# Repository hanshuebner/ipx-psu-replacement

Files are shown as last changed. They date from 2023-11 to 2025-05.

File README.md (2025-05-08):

# Sun SPARCstation IPC/IPX replacement power supply

I've got tired of unsuccessfully trying to repair the APS-02 power
supply that is built into Sun's SPARCstation IPC and IPX workstations,
so I designed this replacement.  It uses two encapsulated power
supplies and a MAX8215 power supply monitoring chip to generate the
SENS signal.

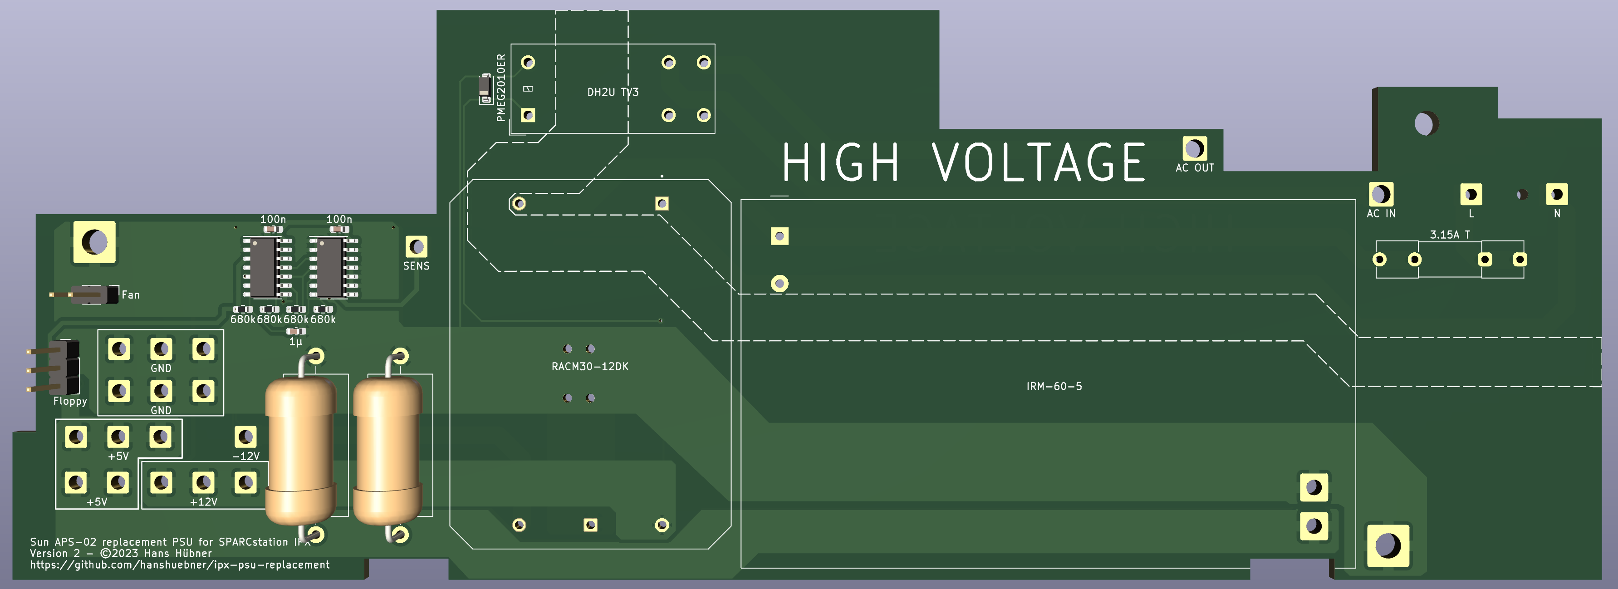
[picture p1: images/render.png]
Rendered v2 PCB


Here's a picture of my version 1 build.  It has the base load
resistors bodged on.  The layout has been revised since:

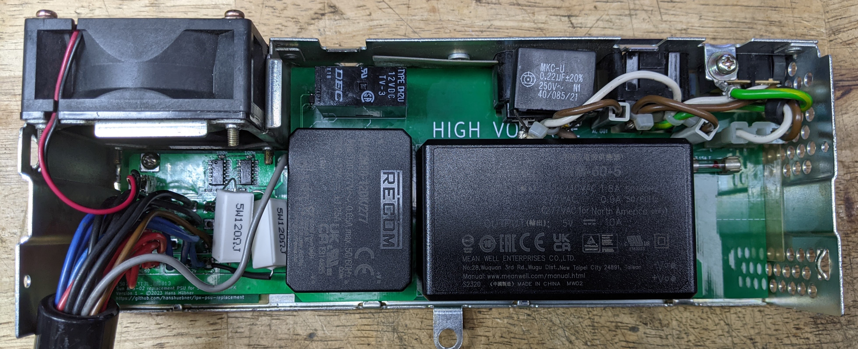
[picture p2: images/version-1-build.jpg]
Version 1 build


Several parts out of the original PSU board are reused and need to be
desoldered:

|Ref |Qnty|Value |Notes |
|----|----|---|---|
|F1  |1 |3.15A T  |Fuse + fuse holder |
|J1  |1 |L |Power input (3 pin, middle pin not connected) |
|J2  |1 |AC IN |Power from IEC input (1 pin) |
|J5  |1 |AC OUT |Power to IEC output (1 pin) |
|J12 |1 |Fan |Power to fan (2 pin) |
|K1  |1 |DH2U TV3 |IEC output relay |
| |1 | |Cable harness including floppy connector |

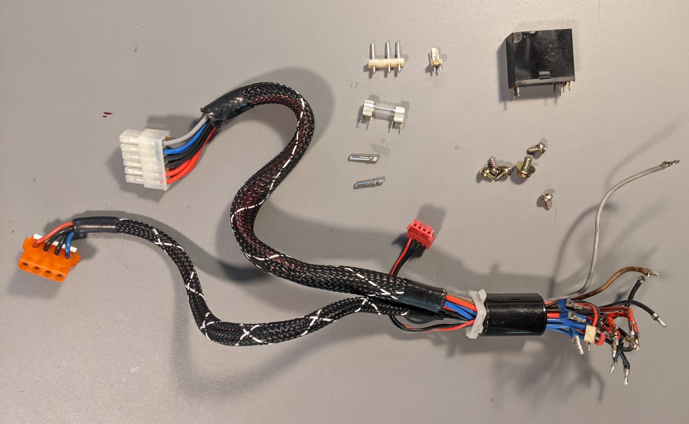
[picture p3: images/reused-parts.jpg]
Reused parts


Another couple of parts need to be bought

|Ref |Qnty|Value |Description |
|---|----|---|---|
|U1 |1 |74HCT11D |Triple 3-input AND, SO-14 |
|U2 |1 |MAX8215CSD |Voltage Monitor IC, SO-14 |
|D1 |1 |PMEG2010ER |20V 1A Planar Schottky barrier rectifier, SOD-123 |
|C1, C2 |2 |100nF |Capacitor bipolar SMD 0603 |
|C3 |1 |1µF |Capacitor bipolar SMD 0603 |
|R1, R2, R3, R4|4 |680kΩ |Resistor SMD 0603 |
|R5, R6 |2 |120Ω |Resistor radial 5W, 20mmx9mmx9mm, 25mm pitch |
|PS1 |1 |IRM-60-5 |MeanWell IRM-60-5 50 Watt AC/DC power supply, 5V, 10A |
|PS2 |1 |RACM30-12DK|RECOM RACM30-12DK/277 30 Watt Dual Output AC/DC power supply, ±12V, ±1250mA |

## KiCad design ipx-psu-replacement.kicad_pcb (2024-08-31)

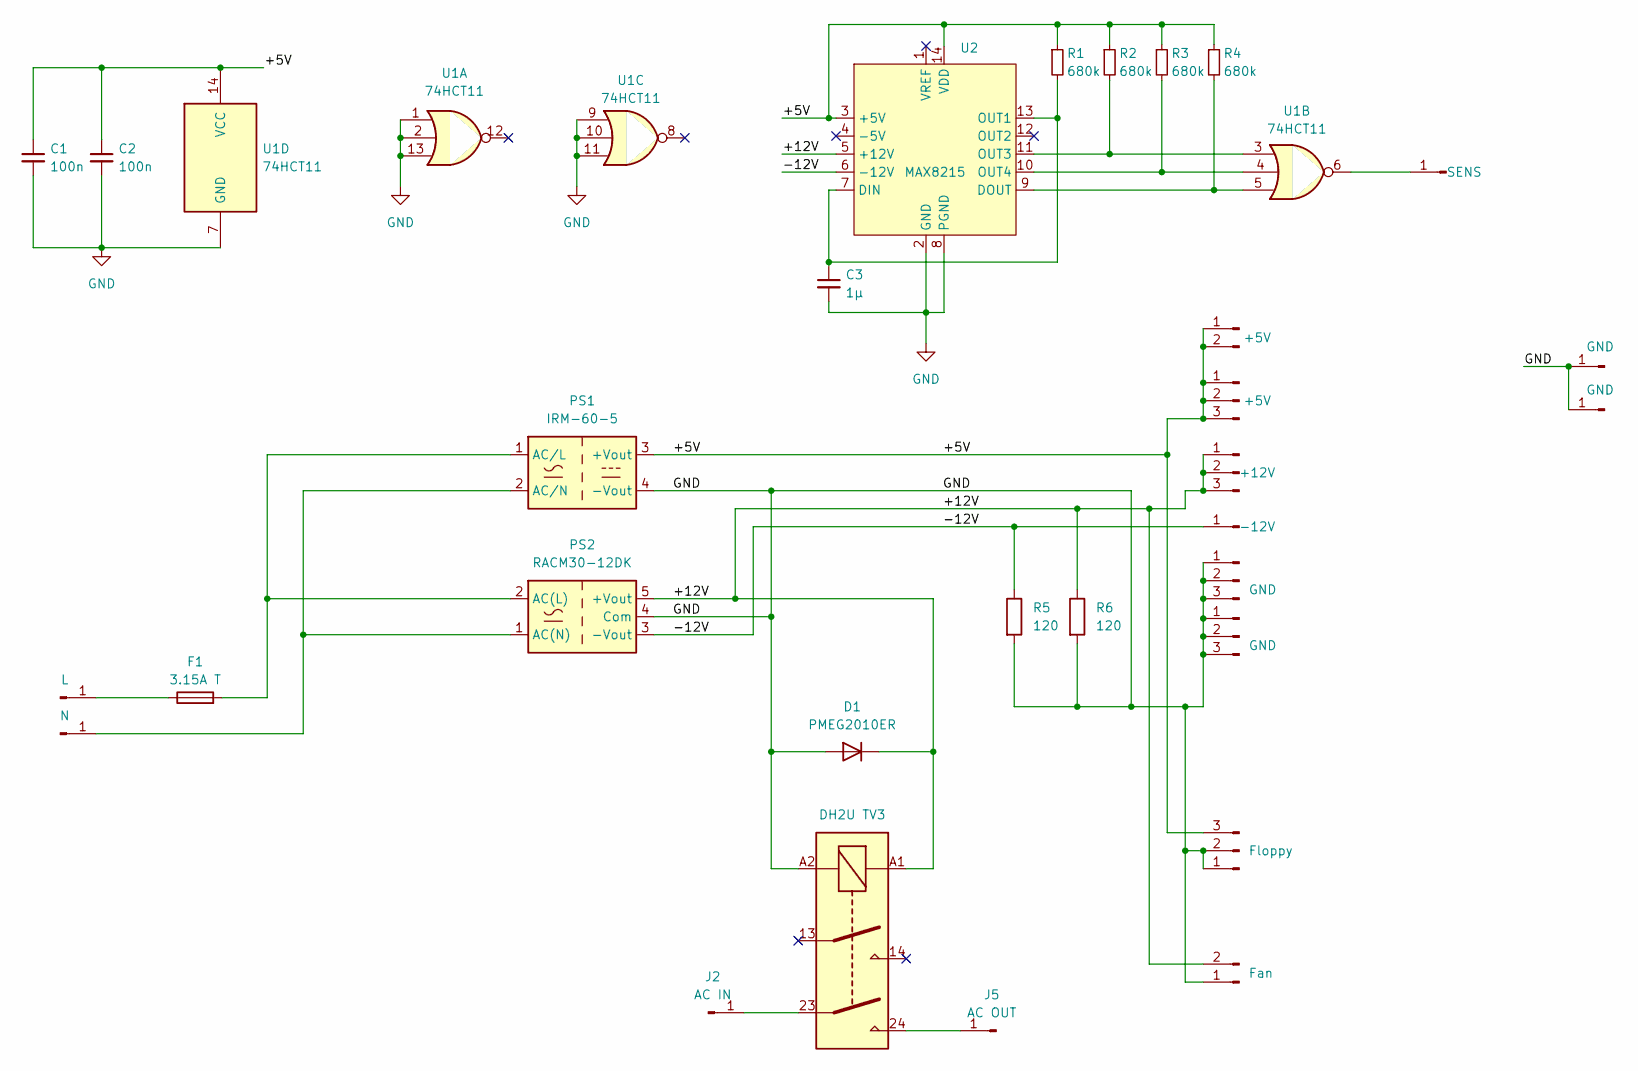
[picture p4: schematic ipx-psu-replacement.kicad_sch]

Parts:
C1, C2: 100n; C_0603_1608Metric_Pad1.08x0.95mm_HandSolder
C3: 1µ; C_0603_1608Metric_Pad1.08x0.95mm_HandSolder
D1: PMEG2010ER; D_SOD-123
F1: 3.15A T; Fuseholder_Clip-5x20mm_Littelfuse_111_Inline_P20.00x5.00mm_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
J1: L; SolderWire-1.5sqmm_1x01_D1.7mm_OD3mm
J2: AC IN; SolderWire-1.5sqmm_1x01_D1.7mm_OD3mm
J3, J11: GND; SolderWire-1.5sqmm_1x03_P6mm_D1.7mm_OD3mm
J4: Floppy; PinHeader_1x03_P2.54mm_Vertical
J5: AC OUT; SolderWire-1.5sqmm_1x01_D1.7mm_OD3mm
J6: N; SolderWire-1.5sqmm_1x01_D1.7mm_OD3mm
J7: +12V; SolderWire-1.5sqmm_1x03_P6mm_D1.7mm_OD3mm
J8: +5V; SolderWire-1.5sqmm_1x02_P6mm_D1.7mm_OD3mm
J9: +5V; SolderWire-1.5sqmm_1x03_P6mm_D1.7mm_OD3mm
J10: -12V; SolderWire-1.5sqmm_1x01_D1.7mm_OD3mm
J12: Fan; PinHeader_1x02_P2.54mm_Vertical
J13: SENS; SolderWire-1.5sqmm_1x01_D1.7mm_OD3mm
J14, J15: GND; SolderWire-2sqmm_1x01_D2mm_OD3.9mm
K1: DH2U TV3; Relay_DPST_Omron_G2RL-2A
PS1: IRM-60-5; Converter_ACDC_MeanWell_IRM-60-xx_THT
PS2: RACM30-12DK; CONV_RACM30-24SK_277
R1, R2, R3, R4: 680k; R_0603_1608Metric_Pad0.98x0.95mm_HandSolder
R5, R6: 120; R_Axial_DIN0922_L20.0mm_D9.0mm_P25.40mm_Horizontal
U1: 74HCT11; SO-14_3.9x8.65mm_P1.27mm
U2: MAX8215; SO-14_3.9x8.65mm_P1.27mm

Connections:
/+5V: C1.1, C2.1, J4.3, J8.1, J8.2, J9.1, J9.2, J9.3, PS1.3 (+Vout), R1.1, R2.1, R3.1, R4.1, U1.14 (VCC), U2.3 (+5V), U2.14 (VDD)
/+12V: D1.1 (K), J7.1, J7.2, J7.3, J12.2, K1.A1, PS2.5 (+Vout), R6.1, U2.5 (+12V)
/-12V: J10.1, PS2.3 (-Vout), R5.1, U2.6 (-12V)
GND: C1.2, C2.2, C3.2, D1.2 (A), J3.1, J3.2, J3.3, J4.1, J4.2, J11.1, J11.2, J11.3, J12.1, J14.1, J15.1, K1.A2, PS1.4 (-Vout), PS2.4 (Com), R5.2, R6.2, U1.1, U1.2, U1.7 (GND), U1.9, U1.10, U1.11, U1.13, U2.2 (GND), U2.8 (PGND)
unnamed: F1.1, J1.1
unnamed: J2.1, K1.23
unnamed: J5.1, K1.24
unnamed: J6.1, PS1.2 (AC/N), PS2.1 (AC(N))
unnamed: J13.1, U1.6
unnamed: F1.2, PS1.1 (AC/L), PS2.2 (AC(L))
unnamed: C3.1, R1.2, U2.7 (DIN), U2.13 (OUT1)
unnamed: R4.2, U1.5, U2.9 (DOUT)
unnamed: R2.2, U1.3, U2.11 (OUT3)
unnamed: R3.2, U1.4, U2.10 (OUT4)

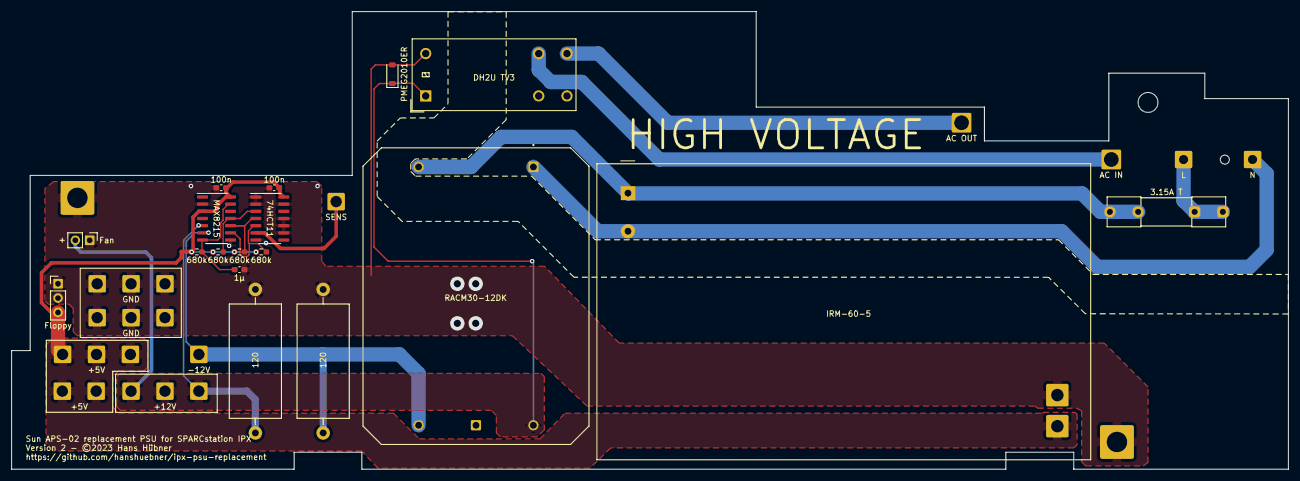
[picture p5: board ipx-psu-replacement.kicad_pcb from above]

Board: 2 copper layers, 226.0 x 81.0 mm, 31 parts (0 on the bottom side), 14 nets.

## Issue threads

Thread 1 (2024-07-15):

Accessory AC Power  - Potentially Incorrect Interpretation

trick-1, 2024-07-15:
Hi there,

I got 5 boards made for my IPX/IPC/Classic collection.

Brining my 1st board up and I noted that the AC IN and AC OUT are not interpreted the same as on the original PSU.

On my original PSU I can clearly see that there is a path from the Active and Neutral to one side of the relay and then from the otherside of the relay to the accessory power connector.  I cannot work out a sound way to wire at this point.

hanshuebner, 2024-07-15:
Can you send a couple photos illustrating the problem?  Maybe you have a different version of the PSU?  Do all the PSUs that you have look the same?  I have used the board for three IPXen and they were all the same, but that is just a small sample of course.

trick-1, 2024-07-15:
In the following the brown and white wires come in from the mains.
The blue and black wires go out to the accessory socket and are switched by the relay.
You can see the mask for the relay on the top side.
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
On this image you can see the foot print of the relay. on the left of the relay is the input from the mains and on the right is the output to the accessory socket.
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
ST3 and ST4 are the output to the accessory socket. ST2 and the hole near the word "SAME" are the inputs from the mains.
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
This is a screen grab of the board from kicad clearly showing no pads on one side of the PSU
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
and the schematic
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

hope that helps

hanshuebner, 2024-07-15:
The PSUs that I have repaired with the replacement board are different from yours in that they only switch one of the two poles of the auxiliary socket.  Given that European sockets generally are not polarized, that could be considered a design flaw.  You could try to bodge a couple of wires to make it work, but I'd probably just leave the aux socket unconnected to avoid having to have bodges on the mains side.

Creating another version of the board for this type of power supply would not be hard, but I don't have the need for that myself at this point and also no machine that I could test it with.  Do all your PSUs look like this?

trick-1, 2024-07-15:
This is the only unit I have. I have 3 more lunch box machines heading my way so will open them up and take a look when they arrive.

Thanks for the confirmation and insight. Agree bodging AC might not be the best idea and will go with the leave disconnected for the time being.

If I get time I will look at making an update to support.

WildOne69, 2024-07-24:
@hanshuebner I have 3 Classics with these Power Supplies (I'm in the USA) and it is the same PCB as @trick-1 pictures above.

hanshuebner, 2024-07-24:
@WildOne69 If you want to send one of your Classics to me, I'd be willing to create a version of the PCB for that PSU type.

WildOne69, 2024-07-24:
@hanshuebner id be willing to send you A defective power supply PCB with the parts removed i would need for a new one but that would depend on what side of the pond you are on.

hanshuebner, 2024-07-24:
@WildOne69 I can't produce something that works without having the system to test it.

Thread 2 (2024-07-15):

Feature Request: Ability to do soft power

trick-1, 2024-07-15:
Some machines like the SPARCclassic LX have software power from the mother board. This allows for power on/off via certain workstation keyboards.

See page 32 and page 77 for some background.
https://docs.oracle.com/cd/E19127-01/sparc.classic/801-2176-13/801-2176-13.pdf

From what I can tell there are 3 wires
GND
Power ON (signal from motherboard)
Power OFF (signal from motherboard)(

Would be fantastic to get this feature added.

hanshuebner, 2024-07-15:
I have no such machine, so I would not be able to verify the board dimensions or try out that version.  If you can donate a broken machine to me, I'll contribute another version :)

trick-1, 2024-07-15:
Same size PSU, the board you have designed fits just fine.

Appreciate the response. If I see more machines with this I may look at how to do this. I also note that I have a 'soft' power switch on the back instead of a mains side power switch. Based on what you have indicated I suspect that that is also different from the board you have.

billsargent, 2025-07-30:
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

But does this current version of the power supply work with the classic just sans soft power on and off?

jabuzz, 2025-08-09:
I recollect that soft power was a feature of all the Sun lunchbox machines. Pressing the power button on your Type5 keyboard powers the machine on and activates the passthrough relay. I never used a Classic, only the IPX.

I don't have a working machine, it's far too far gone to fix up, and besides, my project is to build a stealth "sleeper" workstation inside the IPX case, with no dremel usage, and into which I can plug a Type5 keyboard, etc, and it will just "work". This involves building a PSU into the PSU case and creating a "motherboard" to hold a mini-ITX motherboard. I recently came across this in my YouTube feed, so I wanted to take a look.

Tracing the motherboard and power supply PCBs suggests to me that the grey wire in the PSU wiring harness is connected through to the keyboard for power signalling.

On my power supply PCB I replicated all the curves of the original APS-02 PCB, which was quite some effort. The other comment I would make is that rather than using two mains to low voltage power supplies, a much better approach is a single mains to low voltage PSU and then DC-DC converters to get the other voltages. A single 4"x2" 12V PSU fits comfortably into the casing and makes for easier replacement in the future. Then generate the 5V and -12V using DC-DC converters.  These can be had from drop in modules from the main electronics supplies (Digikey, Mouser, RS, Farnell).

You could do mains to 5V and the two 12V rails from DC-DC converters, but it is more efficient and thus cooler to generate the 5V from the 12V. The main inefficiency in an SMPS is the forward voltage drop over the rectifier diode in the output stage. So for a given total power put you have more current and thus more loss at 5V than 12V. DC-DC converters are stupidly efficient.

Final note the relay is avaliable new, and the wiring harness could be made from scratch. It's bog standard MiniFit Jr 6x2, Molex and Berg connectors, though with as unsual wiring colour choice. That is 12V on blue rather than yellow!!! In PC land 12V is yellow, -12V is blue going right back to the original AT PSU's that predate the Sun lunchbox machines by several years.

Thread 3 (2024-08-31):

U1 footprint

reinauer, 2024-08-31:
The PCB silkscreen suggests that U1 is a 74hct27 nor gate. But the BOM talks about a 74hct11 and gate for U1.

Which one is the correct part?

hanshuebner, 2024-08-31:
What PCB silkscreen are you looking at?  From what I can tell, the version that is on GitHub has the 74HCT11, which is the correct part (48fba2ea6a64b1d7f49c5705dc5846d154136498).

reinauer, 2024-08-31:
Hmmm I'm also not seeing the footprints for the 120ohm resistors.. were the gerbers not updated by any chance?

hanshuebner, 2024-08-31:
Ah, you're looking at the Gerbers.  Thanks for pointing that out, I'll update them now.  Sorry!

reinauer, 2024-08-31:
Yeah, silly me. I ordered a bunch of boards from the gerbers without checking.

hanshuebner, 2024-08-31:
Sorry again!  You should be able to get the boards running anyway if you use a 74HCT11 and scrape off some of the solder mask to solder on the base load resistors.  The Gerbers are updated now, unfortunately too late for you.  Hope you get to revive your IP[CX] nevertheless.

Closed 2024-08-31.

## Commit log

2023-10-12 add power good sensing
    [ipx-psu-replacement.kicad_pcb, ipx-psu-replacement.kicad_sch]
2023-10-12 supervisor circuitry fixed & improved
    [ipx-psu-replacement.kicad_pcb, ipx-psu-replacement.kicad_sch]
2023-10-12 more adjustments
    [ipx-psu-replacement.kicad_pcb, ipx-psu-replacement.kicad_sch]
2023-10-12 v1 - sent to production
    [ipx-psu-replacement.kicad_pcb, ipx-psu-replacement.kicad_sch]
2023-10-31 add base load resistors
    [ipx-psu-replacement.kicad_pcb, ipx-psu-replacement.kicad_sch]
2023-11-01 hct27 -> hct11
    [ipx-psu-replacement.kicad_pcb, ipx-psu-replacement.kicad_sch]
2023-11-01 README with BOM and pictures
2023-11-01 correct mounting hole locations
    [ipx-psu-replacement.kicad_pcb, ipx-psu-replacement.kicad_sch]
2023-12-19 fix part number for +-12V supply
2023-12-19 fix datasheet link
    [ipx-psu-replacement.kicad_sch]
2024-08-31 gerbers updated
    [ipx-psu-replacement.kicad_pcb, ipx-psu-replacement.kicad_sch]
2025-05-08 Fix U1 schematic symbol and flyback diode description
    [ipx-psu-replacement.kicad_sch]

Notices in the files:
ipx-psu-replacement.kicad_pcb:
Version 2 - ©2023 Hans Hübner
